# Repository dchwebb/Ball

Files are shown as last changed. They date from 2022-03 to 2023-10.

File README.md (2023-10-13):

# Ball
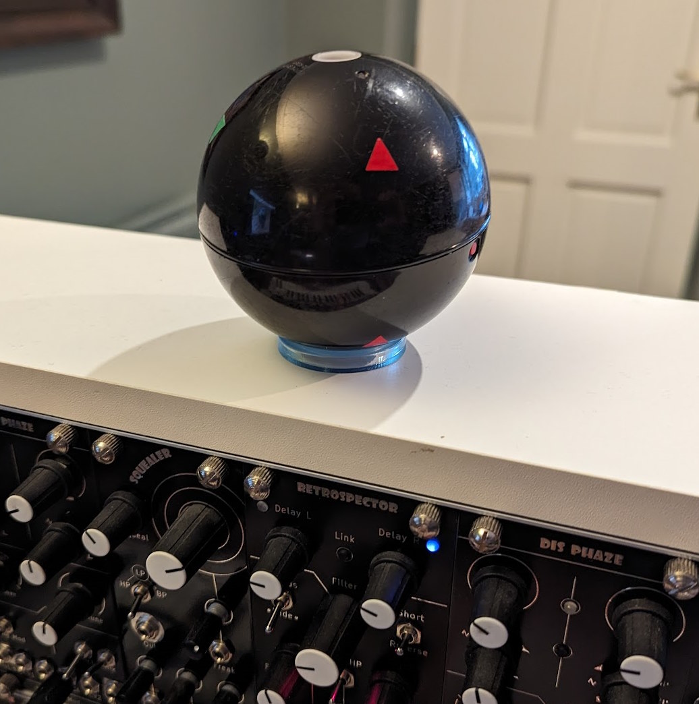
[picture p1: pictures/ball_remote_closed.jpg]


Overview
--------

Ball is a Bluetooth remote controller for a Eurorack modular synthesiser. The remote controller is a sphere containing a PCB with an STM32WB35 BLE transmitter connected to an STM MEMS gyroscope. The remote communicates over Bluetooth Low Energy (BLE) with a base unit. The base unit is a standard Eurorack module that converts the three axis gyroscope information into three control voltages.

Remote
------

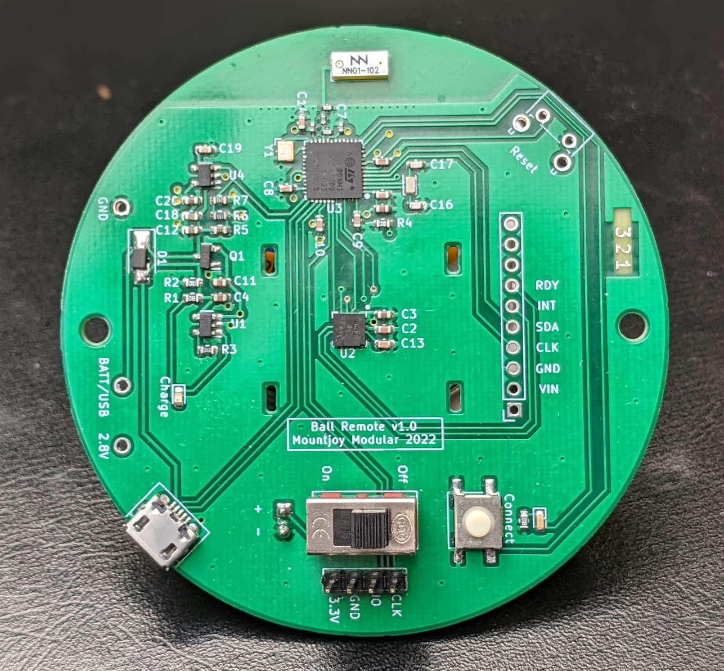
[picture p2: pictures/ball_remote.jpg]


The remote unit is designed around an STM32WB35 and powered from a Li-Po battery which is charged via a USB micro connection. Battery charging uses a MCP73831 Microchip Charge Management Controller. The battery can be isolated with a slide switch. A mosfet switches either the battery or USB power to a 2.8V linear regulator to power the MCU and gyroscope. A combined voltage divider passes the scaled battery voltage to an ADC in the MCU for battery level monitoring. The voltage divider also controls the inhibit line on the LDO to avoid drawing excessive power from the battery.

The 3-D sensing is carried out on an L3GD20 MEMS gyroscope from STM. This communicates with the MCU via full-duplex SPI. Initial prototyping was carried out using I2C on an Adafruit module and the pins for connecting to the module are fitted to the prototype board. The pins exposing the gyroscope ready and interrupt were bodged into the design via the (now unused) I2C pins. This allows waking from sleep mode via motion detection and readings to be taken from the gyroscope as soon as the ready interrupt fires.

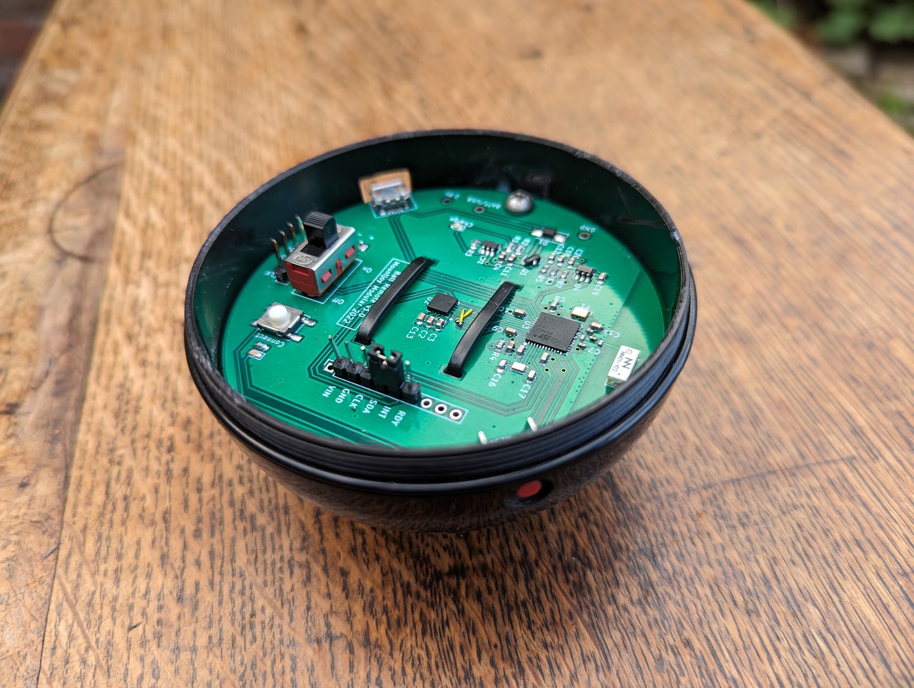
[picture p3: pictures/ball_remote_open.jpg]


The prototype Remote unit was fitted to a black sphere requisitioned from a child's toy.

[Schematic](https://raw.githubusercontent.com/dchwebb/Ball/main/ball_remote_schematic.pdf)

Base Unit
---------

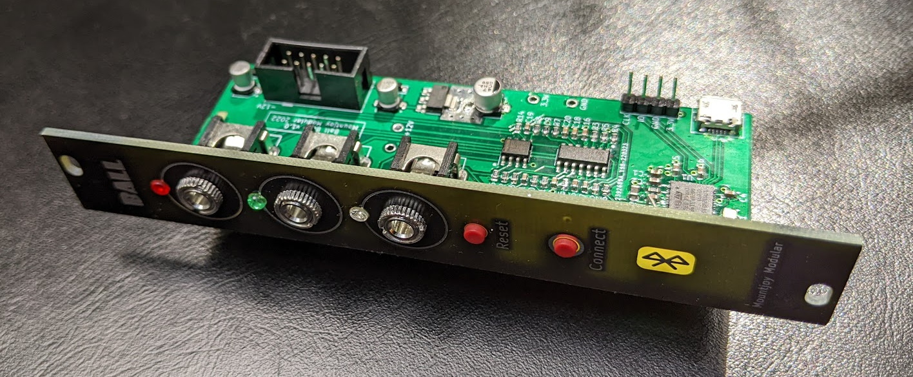
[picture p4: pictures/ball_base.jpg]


The base unit also features an STM32WB35. This receives the 3 dimensional gyroscope data from the remote unit over BLE using the HID Joystick specification. (Theoretically this should mean the unit could also support other BLE game controllers but this has not been tested.)

The STM32WB does not contain any DACs so the gyroscope XYZ data is supplied as PWM data which is filtered and scaled to 0-5V. Three LEDs display the current level of each CV output. An additional blue LED showing BLE connection status is positioned behind a PCB Bluetooth 'window' - ie shines through the FR4 with no solder mask or copper.

[Schematic](https://raw.githubusercontent.com/dchwebb/Ball/main/ball_base_schematic.pdf)

Antennas and Matching Network
-----------------------------

The antenna matching network was designed using largely application notes and guesswork. The matching network consists of an 0402 PI network of capacitor/inductor/capacitor connected to an Ignion NN01_102 antenna. Whilst connection strength could probably be improved if matched with a VNA, communications work well in testing.

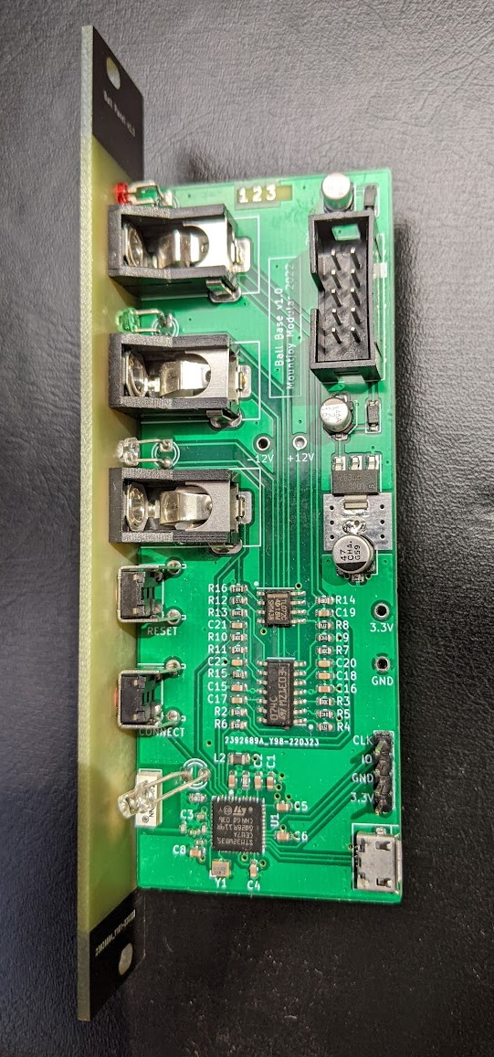
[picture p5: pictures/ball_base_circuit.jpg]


Power Management and Sleep
--------------------------

As the Remote unit is battery powered various systems are used to reduce power consumption:

When the unit is first powered or reset it begins fast advertising which allows for near-instant connections. After a configurable period has elapsed the unit switches to more infrequent advertising. After a further configurable period of inactivity the unit enters shutdown and can be restarted via the reset button.

Once a connection has been established to the base unit the remote will transmit at full speed (around 380Hz). If no motion is detected after a few seconds the unit will slow down the sampling rate to 190Hz and if no motion is detected after a few more seconds will enter sleep mode. The device can woken via motion (using the gyroscope's interrupt pin), or from the base unit (ie to request a battery level update). If woken from motion the sleep process will repeat once the unit is at rest, or if woken via RF will immediately return to sleep.

The Remote unit's USB peripheral is disabled unless a battery reading of 100% is registered (ie the unit is connected to USB and powered via VBUS). If USB is enabled current draw is around 2mA higher than usual. a USB serial command will also momentarily wake the unit if sleeping.

Measured current consumption of the remote (MCU and all other hardware) is measured as approximately:

- Advertising: 13mA
- Connected: 16mA
- Sleep: 10mA
- Shutdown: 0.4mA

USB Serial Console
------------------

Both the base and remote have USB serial consoles providing a range of diagnostic and configuration information:

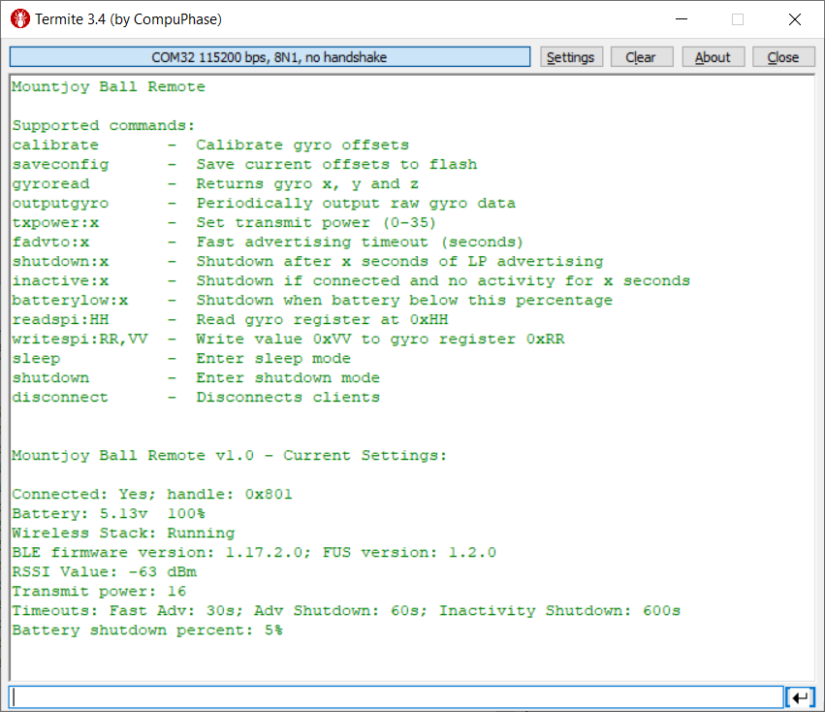
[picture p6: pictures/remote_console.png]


Development Software
--------------------

- Schematic and PCB design done in Kicad v6/7.
- Firmware developed in STM32CubeIDE v1.13.2.

Errata
------

Remote:

- SPI MOSI and MISO connections swapped
- Gyroscope Interrupt and Ready pins bodged onto unused I2C pins
- Mosfet Q1 source and drain pins swapped
- Battery charging and monitoring circuit could be improved (eg using a dedicated Battery Management IC such as TI's BQ24079QWRGTRQ1)

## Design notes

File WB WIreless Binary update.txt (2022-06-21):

- Binary locations
C:\Users\Dominic\STM32Cube\Repository\STM32Cube_FW_WB_V1.13.3\Projects\STM32WB_Copro_Wireless_Binaries\STM32WB3x

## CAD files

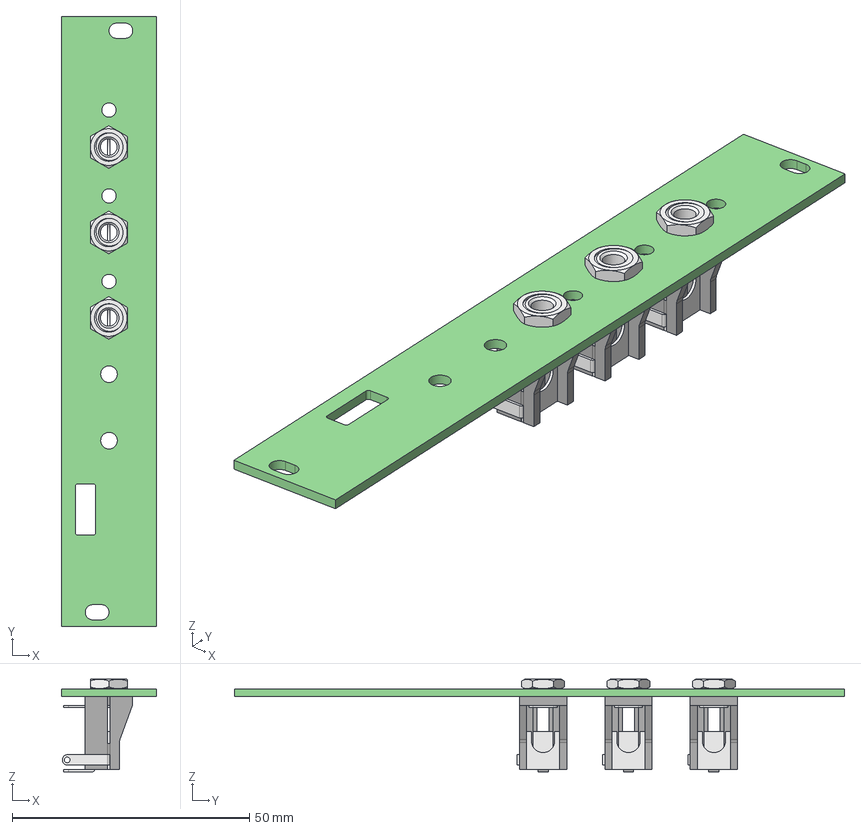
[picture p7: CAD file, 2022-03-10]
Hardware/Graphics/Ball_Base_Panel.step
20.0 x 128.5 x 19.5 mm
Ball_Base_Panel PCB

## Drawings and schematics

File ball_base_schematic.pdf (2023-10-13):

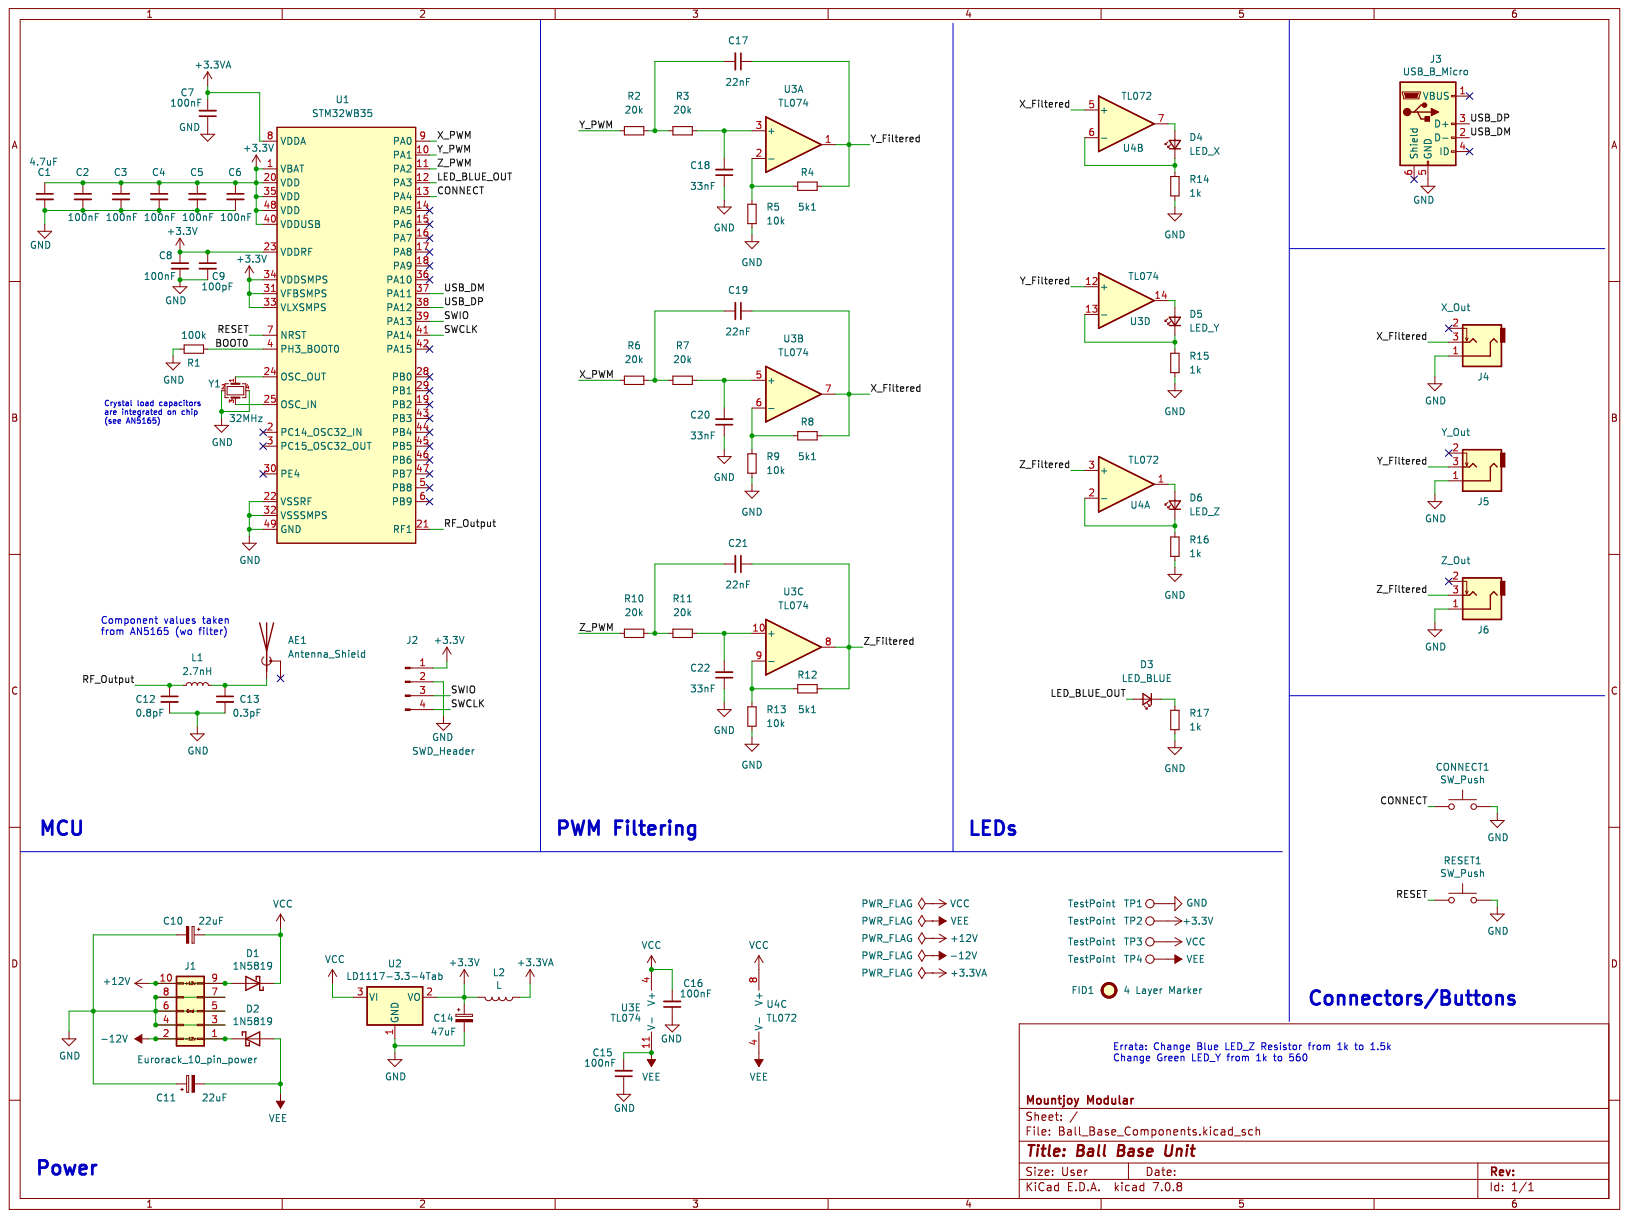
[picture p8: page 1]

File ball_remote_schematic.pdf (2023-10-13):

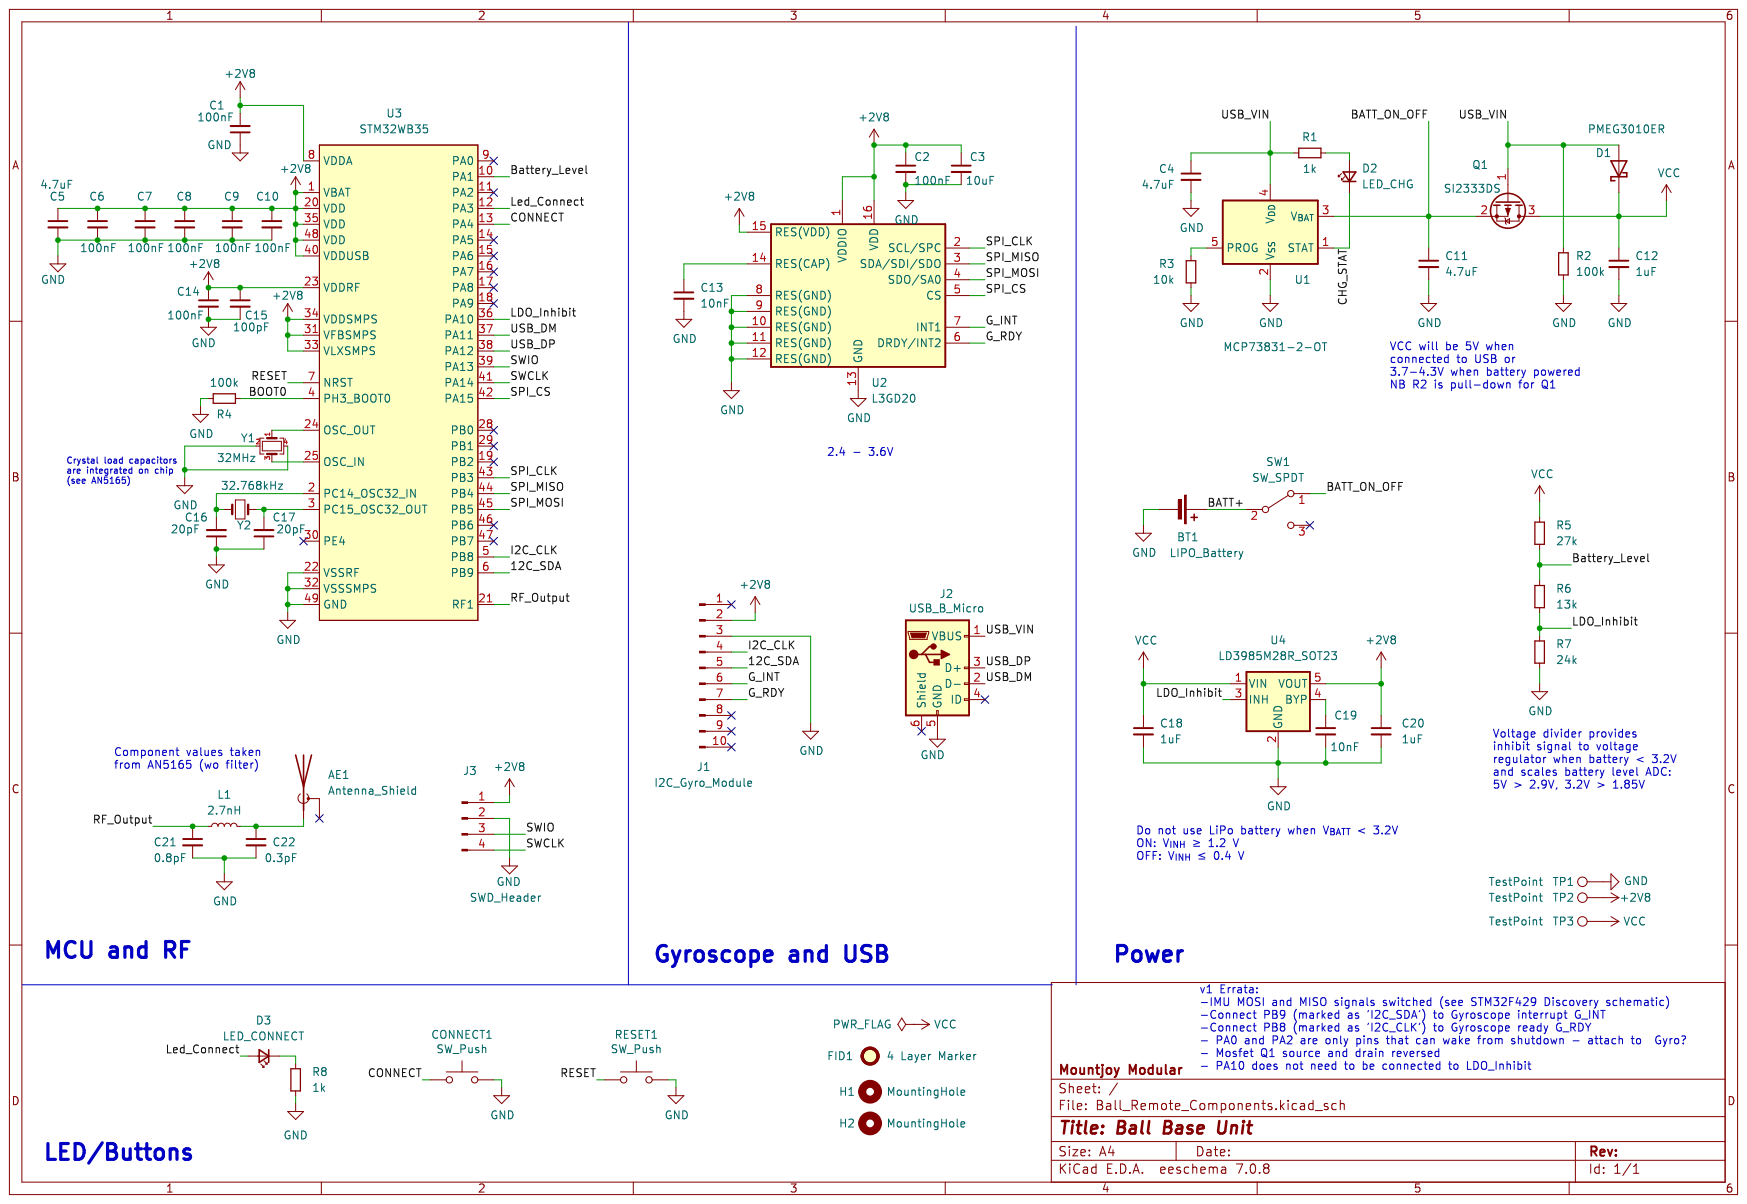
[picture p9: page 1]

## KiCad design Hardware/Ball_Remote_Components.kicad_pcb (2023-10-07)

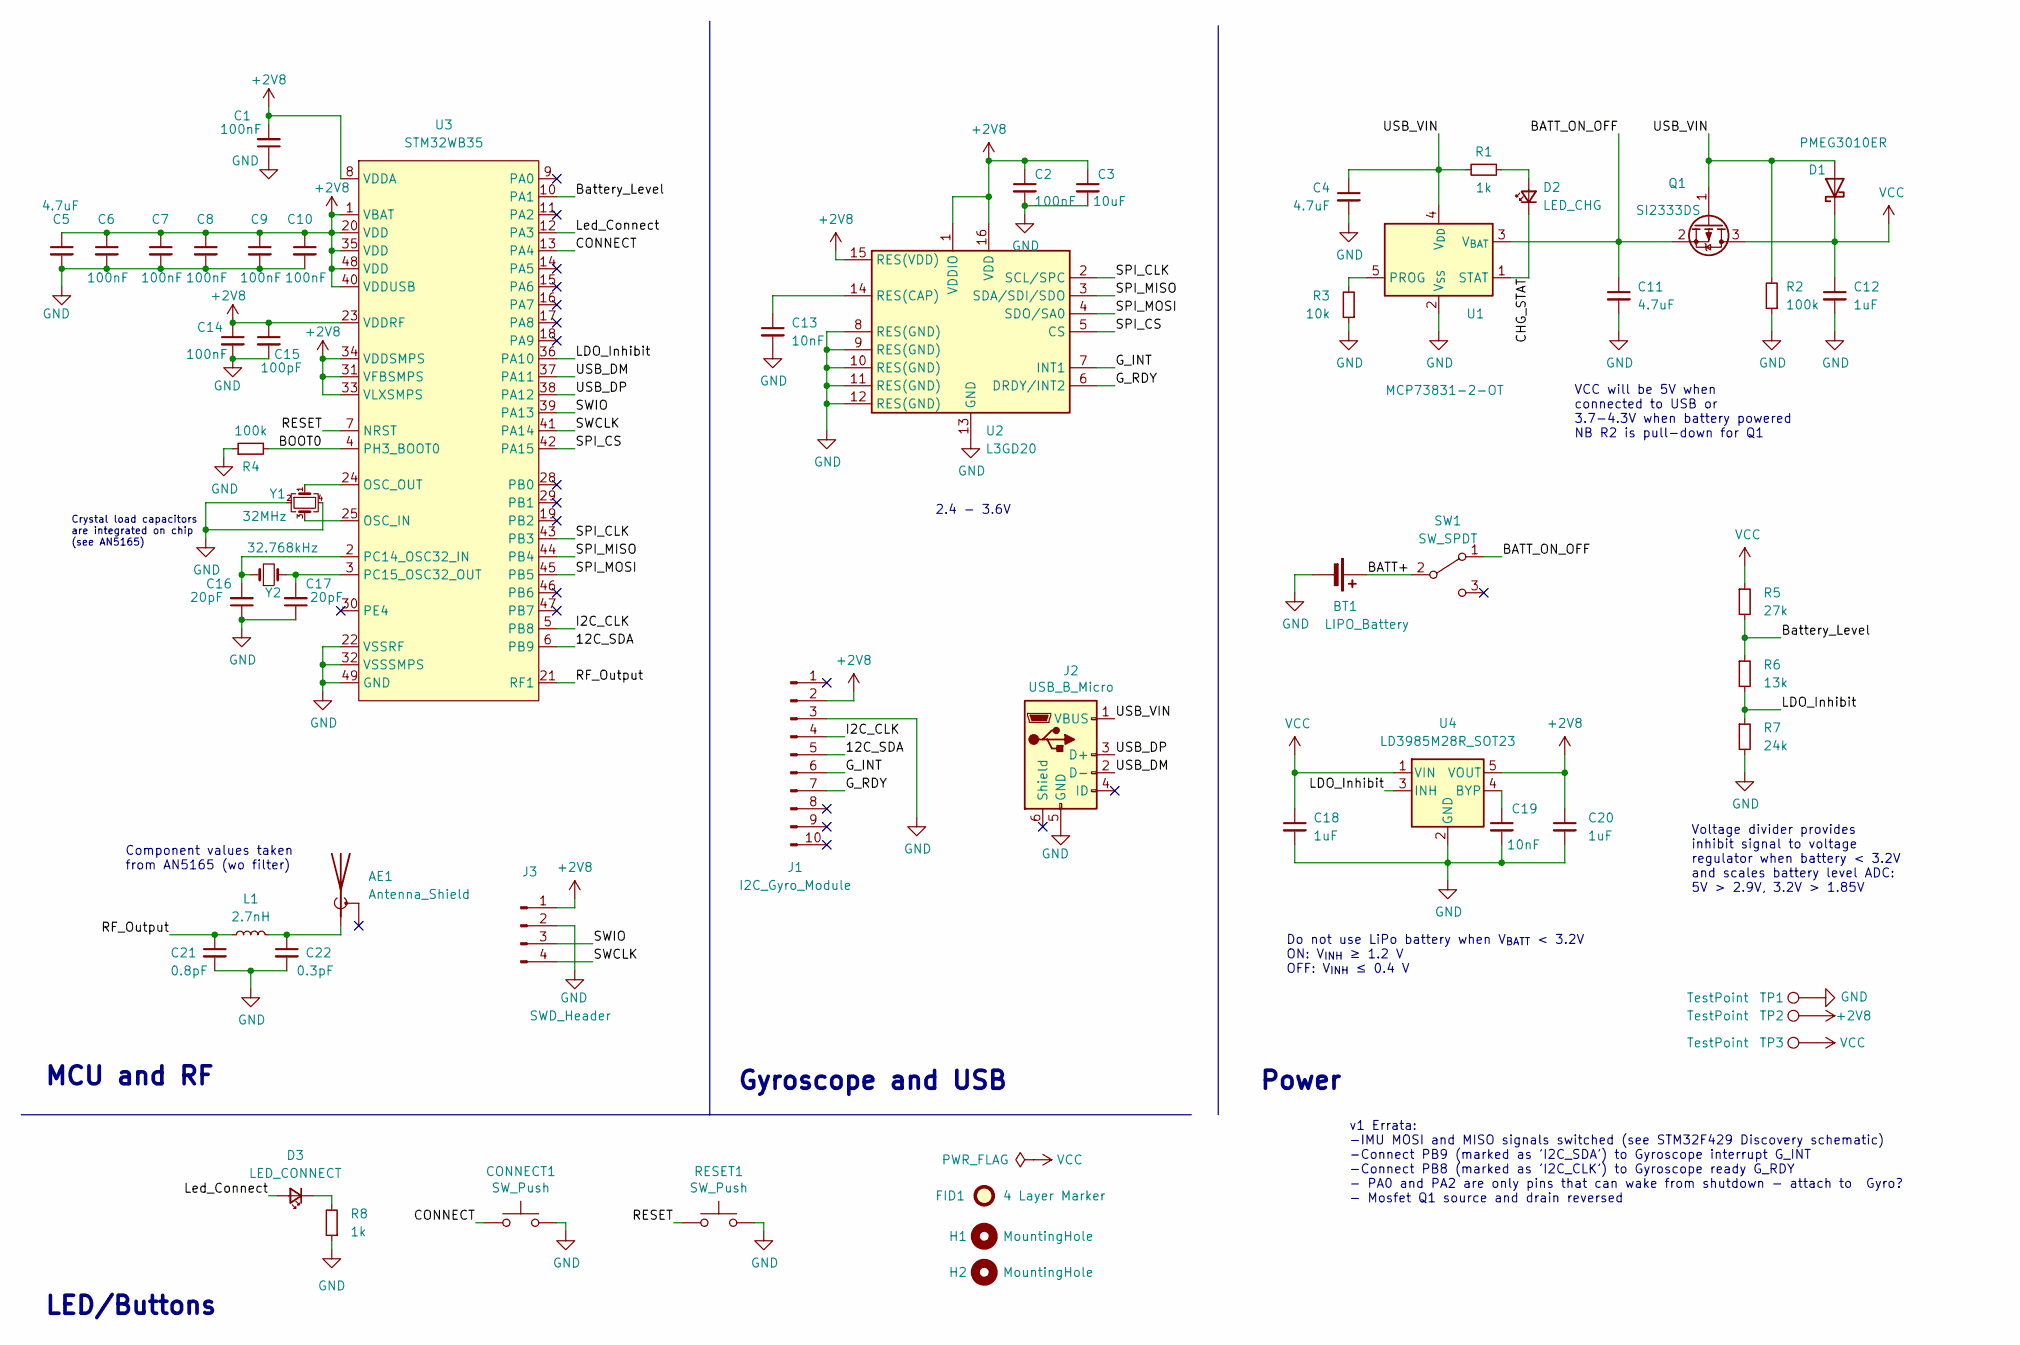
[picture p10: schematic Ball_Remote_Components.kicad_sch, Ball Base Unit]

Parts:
AE1: Antenna_Shield; NN01_102
BT1: LIPO_Battery; PinHeader_1x02_P2.54mm_Vertical
C1, C2, C6, C8, C9, C10, C14: 100nF; C_0603_1608Metric
C3: 10uF; C_0603_1608Metric
C4, C5, C11: 4.7uF; C_0603_1608Metric
C7: 100nF; C_0402_1005Metric
C12, C18, C20: 1uF; C_0603_1608Metric
C13, C19: 10nF; C_0603_1608Metric
C15: 100pF; C_0402_1005Metric
C16, C17: 20pF; C_0603_1608Metric
C21: 0.8pF; C_0402_1005Metric
C22: 0.3pF; C_0402_1005Metric
CONNECT1: SW_Push; SW_SPST_EVQQ2
D1: PMEG3010ER; D_SMA
D2: LED_CHG; LED_0603_1608Metric
D3: LED_CONNECT; LED_0603_1608Metric
FID1: 4 Layer Marker; 4_Layer_Markers
H1, H2: MountingHole; MountingHole_3.2mm_M3
J1: I2C_Gyro_Module; PinSocket_1x10_P2.54mm_Vertical
J2: USB_B_Micro; USB_Micro-B_Amphenol
J3: SWD_Header; SWD_header
L1: 2.7nH; L_0402_1005Metric
Q1: SI2333DS; SOT-23
R1: 1k; R_0603_1608Metric; Part_Number C25803
R2, R4: 100k; R_0603_1608Metric; Part_Number C25803
R3: 10k; R_0603_1608Metric; Part_Number C25803
R5: 27k; R_0603_1608Metric; Part_Number C25803
R6: 13k; R_0603_1608Metric; Part_Number C25803
R7: 24k; R_0603_1608Metric; Part_Number C25803
R8: 1k; R_0603_1608Metric
RESET1: SW_Push; SW_Tactile_SPST_Angled_PTS645Vx58-2LFS
SW1: SW_SPDT; SPDT_Slide_Switch
TP1, TP2, TP3: TestPoint; 1.3mm_Test_Point
U1: MCP73831-2-OT; SOT-23-5
U2: L3GD20; LGA-16_4x4mm_P0.65mm_LayoutBorder4x4y
U3: STM32WB35; QFN-48-1EP_7x7mm_P0.5mm_EP5.15x5.15mm_ThermalVias
U4: LD3985M28R_SOT23; SOT-23-5
Y1: 32MHz; Crystal_SMD_Abracon_ABM10-4Pin_2.5x2.0mm
Y2: 32.768kHz; Crystal_SMD_2012-2Pin_2.0x1.2mm

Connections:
+2V8: C1.2, C2.1, C3.1, C5.1, C6.1, C7.1, C8.1, C9.1, C10.1, C14.1, C15.1, C20.1, J1.2, J3.1, TP2.1, U2.1 (VDDIO), U2.15 (RES(VDD)), U2.16 (VDD), U3.1 (VBAT), U3.8 (VDDA), U3.20 (VDD), U3.23 (VDDRF), U3.31 (VFBSMPS), U3.33 (VLXSMPS), U3.34 (VDDSMPS), U3.35 (VDD), U3.40 (VDDUSB), U3.48 (VDD), U4.5 (VOUT)
/12C_SDA: J1.5, U3.6 (PB9)
/BATT+: BT1.1 (+), SW1.2 (B)
/BATT_ON_OFF: C11.1, Q1.2 (S), SW1.1 (A), U1.3 (V_{BAT})
/BOOT0: R4.2, U3.4 (PH3_BOOT0)
/Battery_Level: R5.2, R6.1, U3.10 (PA1)
/CHG_STAT: D2.1 (K), U1.1 (STAT)
/CONNECT: CONNECT1.1, U3.13 (PA4)
/G_INT: J1.6, U2.7 (INT1)
/G_RDY: J1.7, U2.6 (DRDY/INT2)
/I2C_CLK: J1.4, U3.5 (PB8)
/LDO_Inhibit: R6.2, R7.1, U3.36 (PA10), U4.3 (INH)
/Led_Connect: D3.2 (A), U3.12 (PA3)
/RESET: RESET1.1, U3.7 (NRST)
/RF_Output: C21.1, L1.1, U3.21 (RF1)
/SPI_CLK: U2.2 (SCL/SPC), U3.43 (PB3)
/SPI_CS: U2.5 (CS), U3.42 (PA15)
/SPI_MISO: U2.3 (SDA/SDI/SDO), U3.44 (PB4)
/SPI_MOSI: U2.4 (SDO/SA0), U3.45 (PB5)
/SWCLK: J3.4, U3.41 (PA14)
/SWIO: J3.3, U3.39 (PA13)
/USB_DM: J2.2 (D-), U3.37 (PA11)
/USB_DP: J2.3 (D+), U3.38 (PA12)
/USB_VIN: C4.1, D1.2 (A), J2.1 (VBUS), Q1.1 (G), R1.2, R2.2, U1.4 (V_{DD})
GND: BT1.2 (-), C1.1, C2.2, C3.2, C4.2, C5.2, C6.2, C7.2, C8.2, C9.2, C10.2, C11.2, C12.2, C13.2, C14.2, C15.2, C16.1, C17.1, C18.2, C19.2, C20.2, C21.2, C22.2, CONNECT1.2, J1.3, J2.5 (GND), J3.2, R2.1, R3.1, R4.1, R7.2, R8.1, RESET1.2, TP1.1, U1.2 (V_{SS}), U2.8 (RES(GND)), U2.9 (RES(GND)), U2.10 (RES(GND)), U2.11 (RES(GND)), U2.12 (RES(GND)), U2.13 (GND), U3.22 (VSSRF), U3.32 (VSSSMPS), U3.49 (GND), U4.2 (GND), Y1.2, Y1.4
unnamed: AE1.1 (A), C22.1, L1.2
unnamed: D2.2 (A), R1.1
unnamed: D3.1 (K), R8.2
unnamed: R3.2, U1.5 (PROG)
unnamed: C13.1, U2.14 (RES(CAP))
unnamed: U3.25 (OSC_IN), Y1.3
unnamed: U3.24 (OSC_OUT), Y1.1
unnamed: C16.2, U3.2 (PC14_OSC32_IN), Y2.1
unnamed: C17.2, U3.3 (PC15_OSC32_OUT), Y2.2
unnamed: C19.1, U4.4 (BYP)
VCC: C12.1, C18.1, D1.1 (K), Q1.3 (D), R5.1, TP3.1, U4.1 (VIN)

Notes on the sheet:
MCU and RF
Do not use LiPo battery when V_{BATT} < 3.2V ON: V_{INH} ≥ 1.2 V OFF: V_{INH} ≤ 0.4 V
Power
Gyroscope and USB
Component values taken from AN5165 (wo filter)
Voltage divider provides inhibit signal to voltage regulator when battery < 3.2V and scales battery level ADC: 5V > 2.9V, 3.2V > 1.85V
2.4 - 3.6V
LED/Buttons
VCC will be 5V when connected to USB or 3.7-4.3V when battery powered NB R2 is pull-down for Q1
v1 Errata: -IMU MOSI and MISO signals switched (see STM32F429 Discovery schematic) -Connect PB9 (marked as 'I2C_SDA') to Gyroscope interrupt G_INT -Connect PB8 (marked as 'I2C_CLK') to Gyroscope ready G_RDY - PA0 and PA2 are only pins that can wake from shutdown - attach to Gyro? - Mosfet Q1 source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
Crystal load capacitors are integrated on chip (see AN5165)

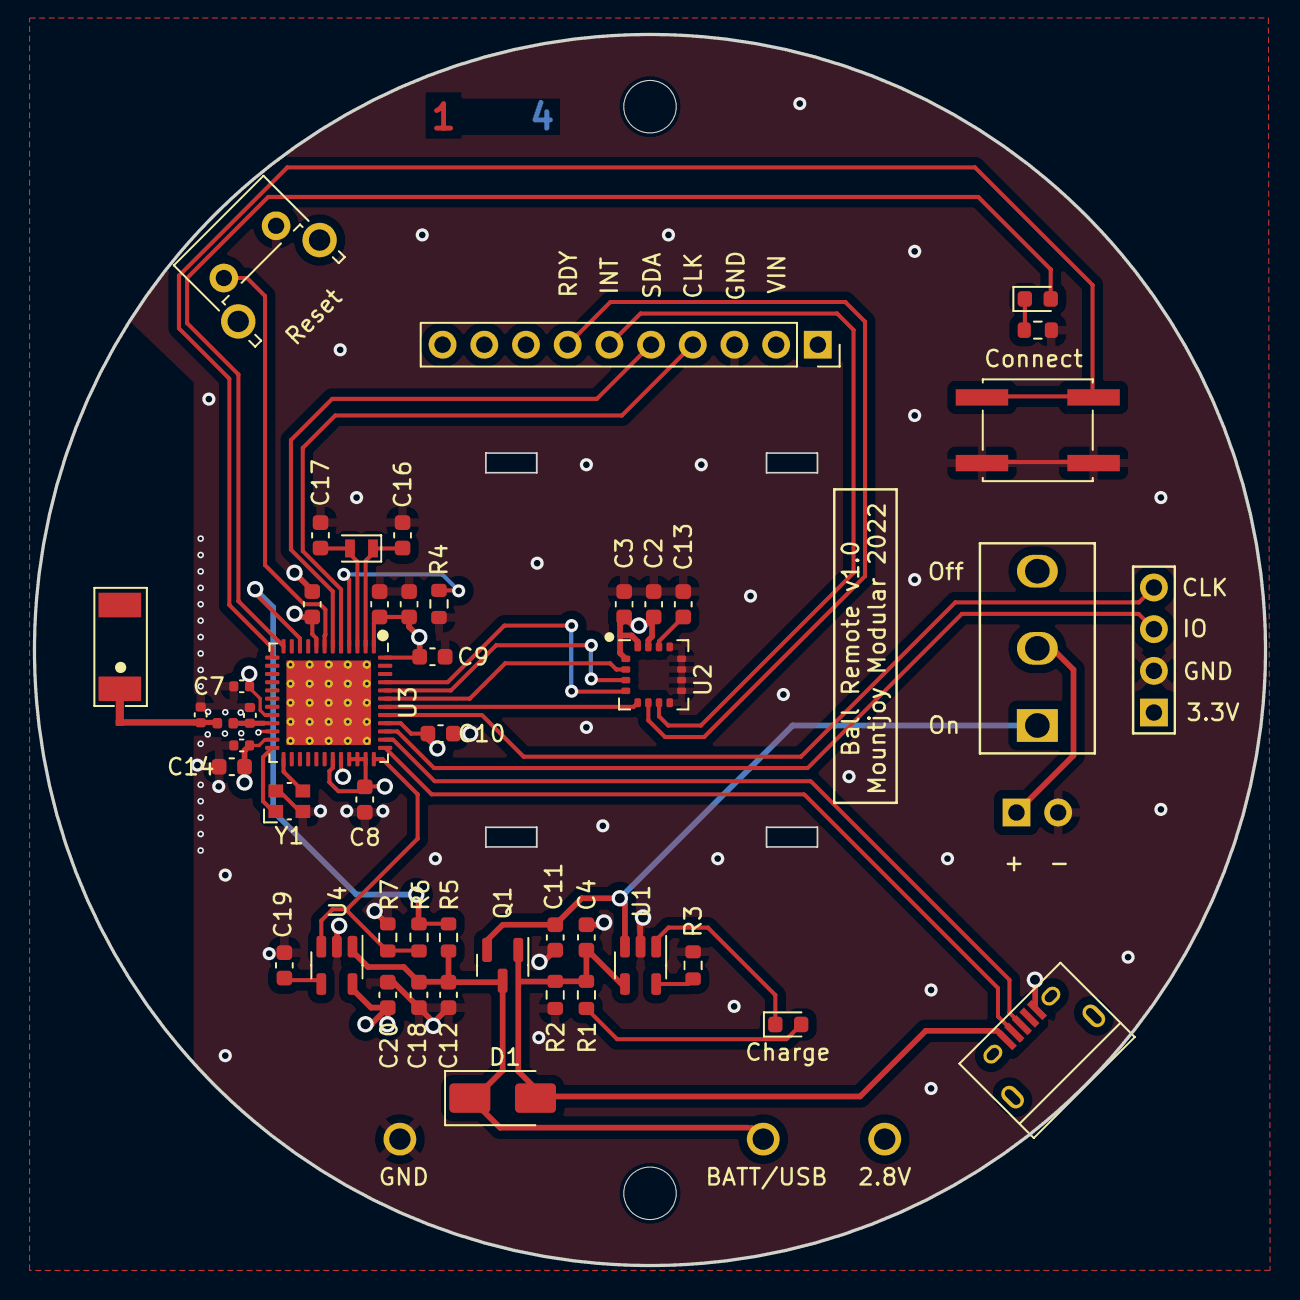
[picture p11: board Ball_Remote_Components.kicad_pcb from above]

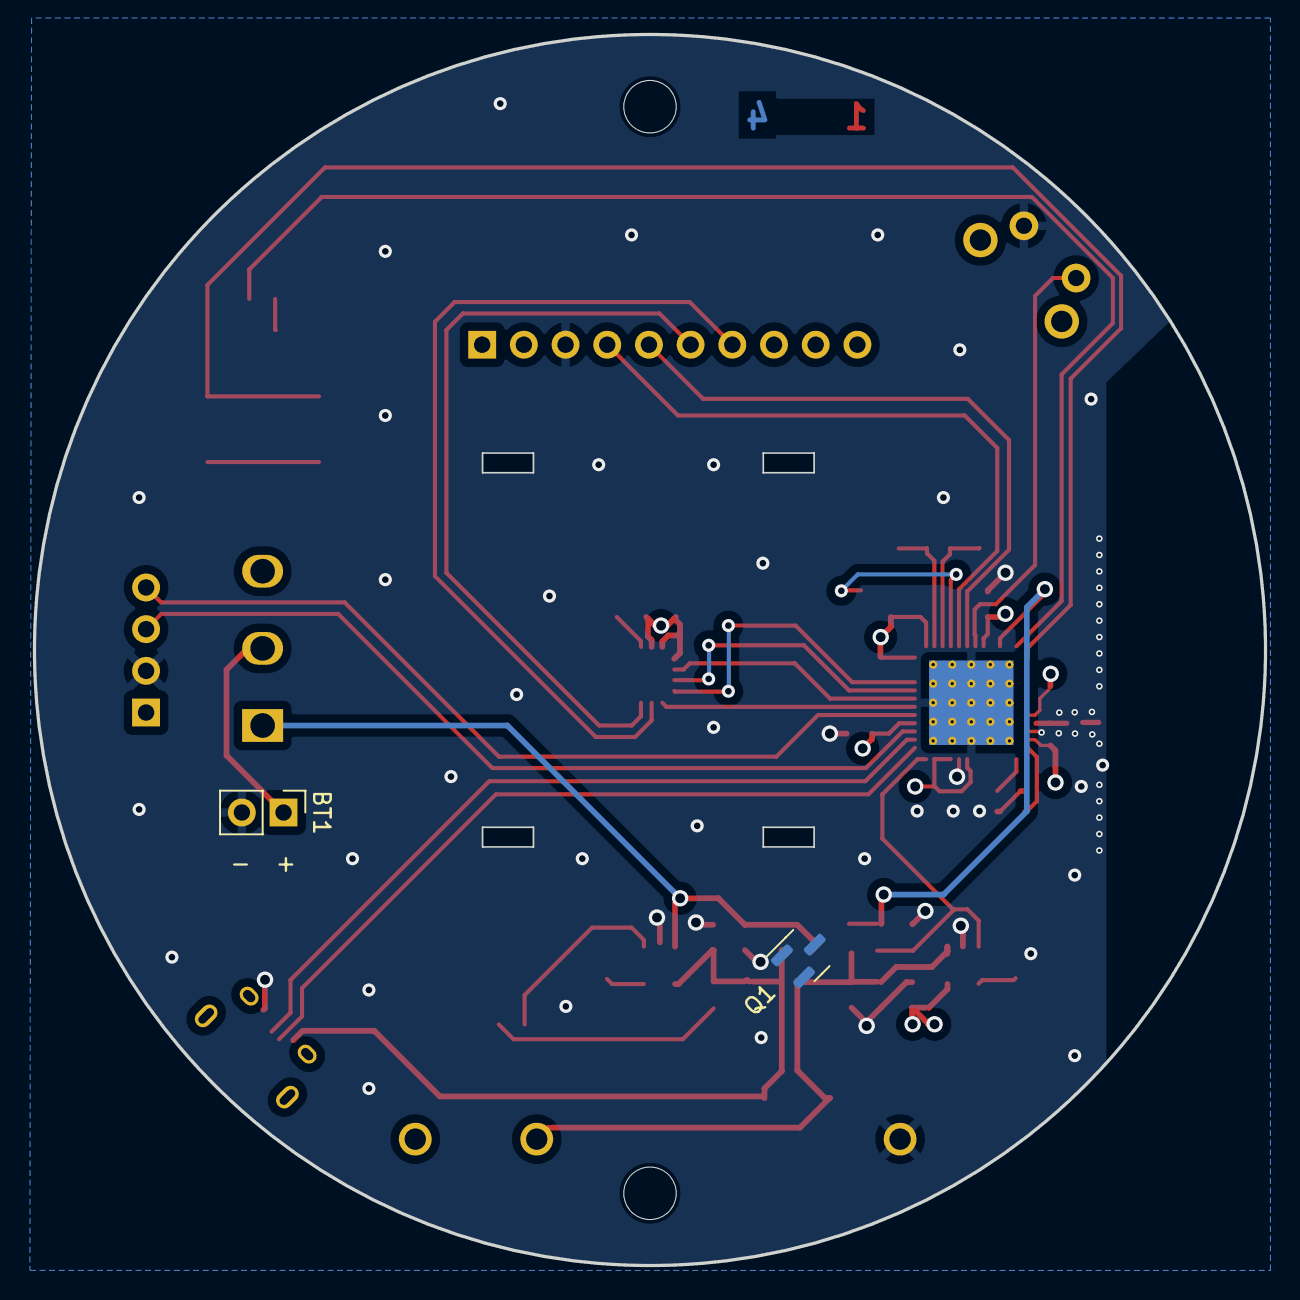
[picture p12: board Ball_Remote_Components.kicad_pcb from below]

Board: 4 copper layers, 75.0 x 75.0 mm, 56 parts (2 on the bottom side), 36 nets.

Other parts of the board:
Q1#2: SI2333DS; SOT-23

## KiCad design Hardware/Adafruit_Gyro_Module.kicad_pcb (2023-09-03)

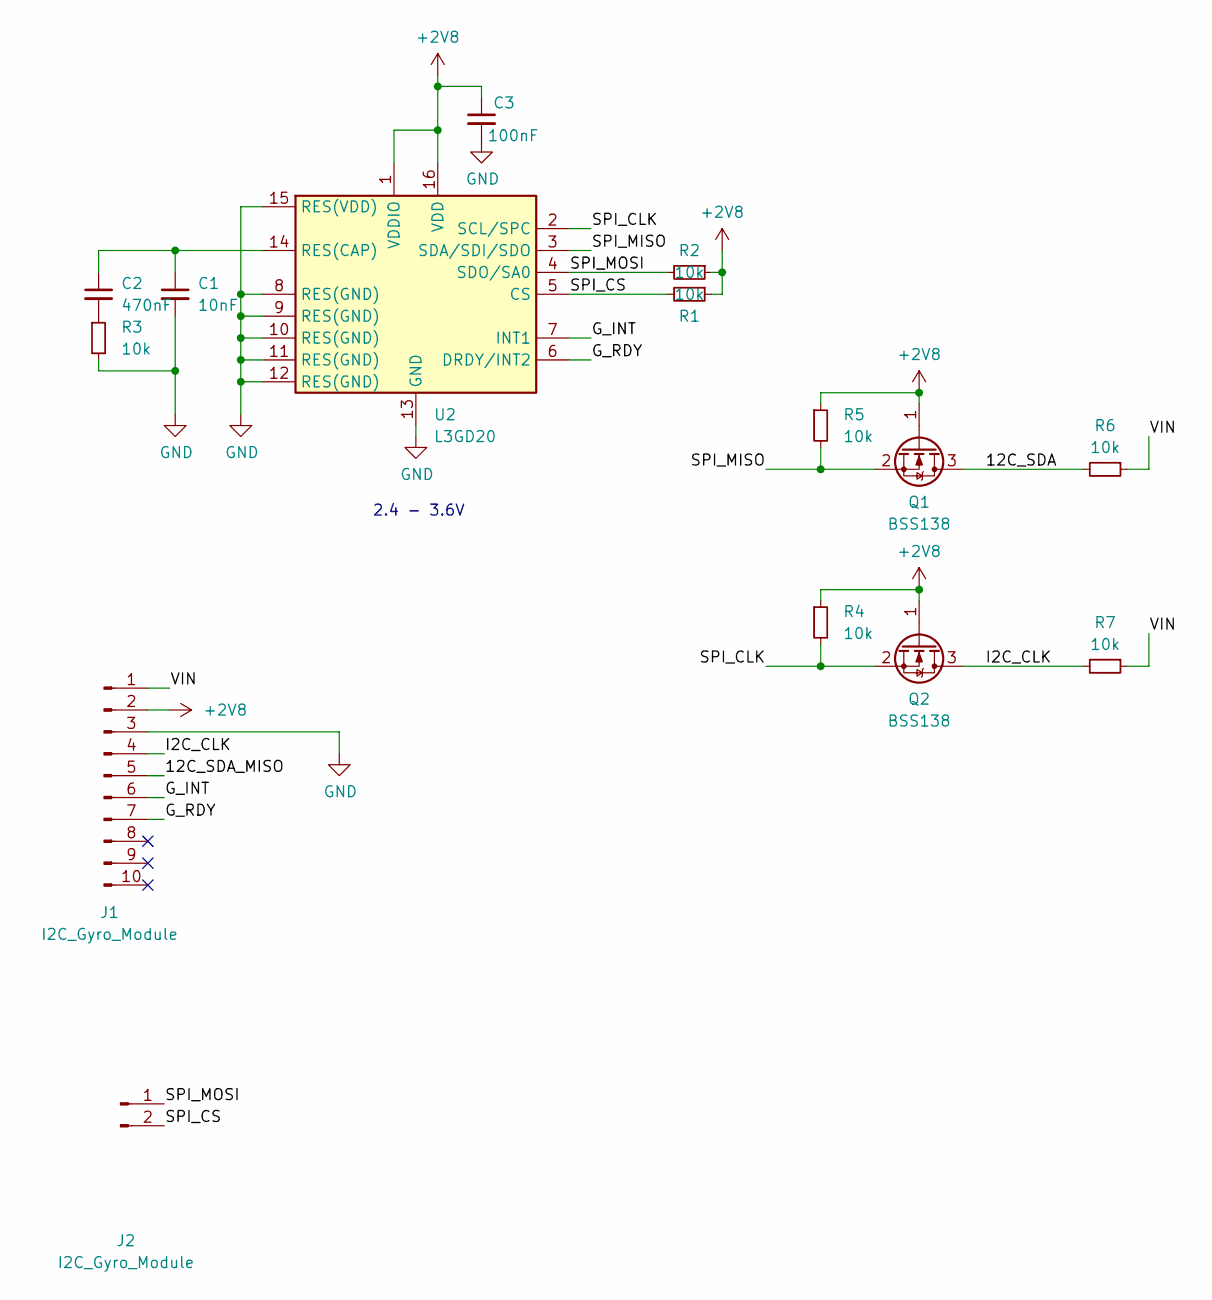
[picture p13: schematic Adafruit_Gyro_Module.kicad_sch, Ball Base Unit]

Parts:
C1: 10nF; C_0603_1608Metric
C2: 470nF; C_0603_1608Metric
C3: 100nF; C_0603_1608Metric
J1: I2C_Gyro_Module; PinSocket_1x10_P2.54mm_Vertical
J2: I2C_Gyro_Module; PinSocket_1x02_P2.54mm_Vertical
Q1, Q2: BSS138; SOT-23
R1, R2, R3, R4, R5, R6, R7: 10k; R_0603_1608Metric; Part_Number C25803
U2: L3GD20; LGA-16_4x4mm_P0.65mm_LayoutBorder4x4y

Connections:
+2V8: C3.1, J1.2, Q1.1 (G), Q2.1 (G), R1.1, R2.1, R4.1, R5.1, U2.1 (VDDIO), U2.16 (VDD)
/12C_SDA: Q1.3 (D), R6.2
/12C_SDA_MISO: J1.5
/G_INT: J1.6, U2.7 (INT1)
/G_RDY: J1.7, U2.6 (DRDY/INT2)
/I2C_CLK: J1.4, Q2.3 (D), R7.2
/SPI_CLK: Q2.2 (S), R4.2, U2.2 (SCL/SPC)
/SPI_CS: J2.2, R1.2, U2.5 (CS)
/SPI_MISO: Q1.2 (S), R5.2, U2.3 (SDA/SDI/SDO)
/SPI_MOSI: J2.1, R2.2, U2.4 (SDO/SA0)
/VIN: J1.1, R6.1, R7.1
GND: C1.2, C3.2, J1.3, R3.2, U2.8 (RES(GND)), U2.9 (RES(GND)), U2.10 (RES(GND)), U2.11 (RES(GND)), U2.12 (RES(GND)), U2.13 (GND), U2.15 (RES(VDD))
unnamed: C2.2, R3.1
unnamed: C1.1, C2.1, U2.14 (RES(CAP))

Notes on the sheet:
2.4 - 3.6V

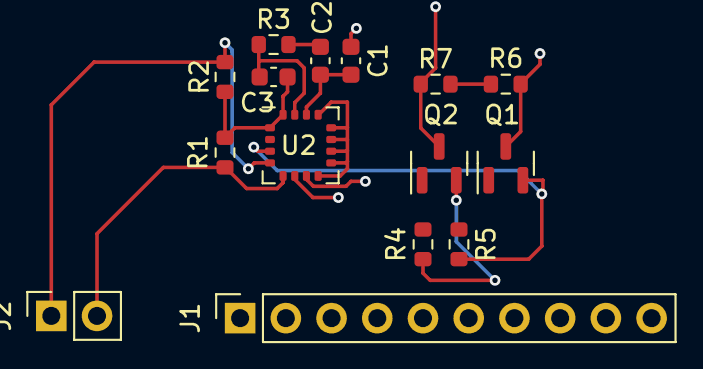
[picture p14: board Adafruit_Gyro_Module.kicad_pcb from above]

Board: 2 copper layers, 15 parts (0 on the bottom side), 13 nets.

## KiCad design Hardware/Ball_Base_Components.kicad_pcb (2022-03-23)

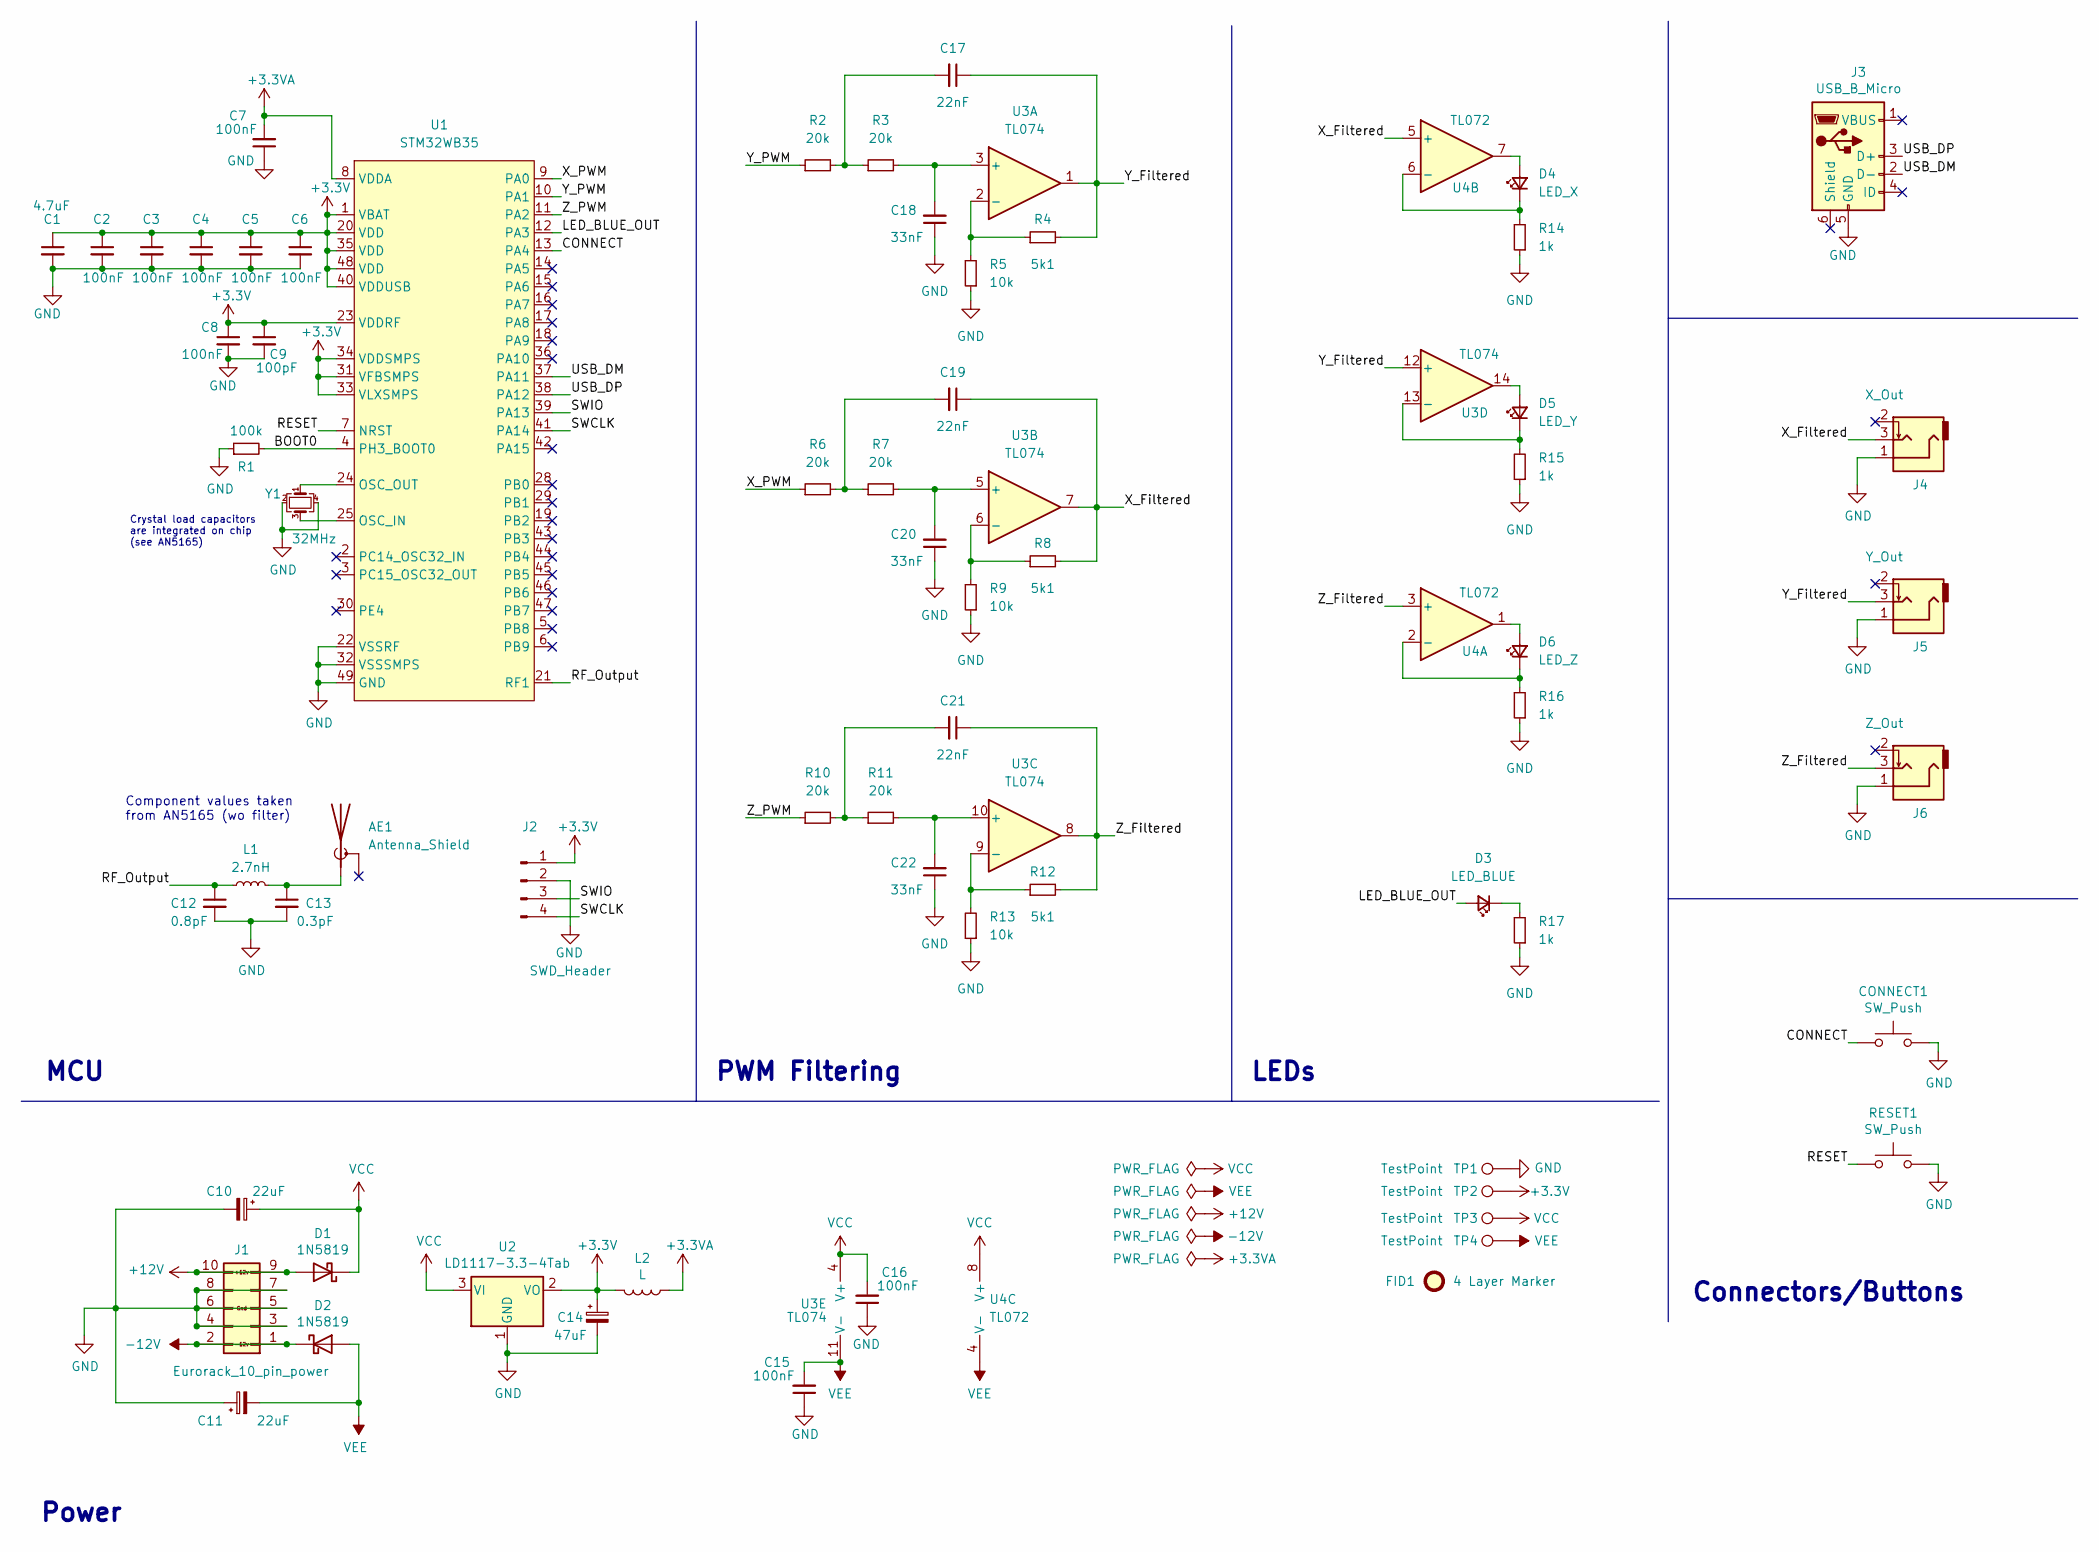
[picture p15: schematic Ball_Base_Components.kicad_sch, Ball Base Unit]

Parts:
AE1: Antenna_Shield; NN01_102
C1: 4.7uF; C_0603_1608Metric
C2, C4, C5, C6, C7, C8, C15, C16: 100nF; C_0603_1608Metric
C3: 100nF; C_0402_1005Metric
C9: 100pF; C_0402_1005Metric
C10: 22uF; CP_Elec_4x5.4; Part_Number C134798
C11: 22uF; CP_Elec_4x5.4; Part_Number C134793
C12: 0.8pF; C_0402_1005Metric
C13: 0.3pF; C_0402_1005Metric
C14: 47uF; CP_Elec_5x5.8; Part_Number C134798
C17, C19, C21: 22nF; C_0603_1608Metric
C18, C20, C22: 33nF; C_0603_1608Metric
CONNECT1: SW_Push; SW_Tactile_SPST_Angled_PTS645Vx58-2LFS
D1, D2: 1N5819; D_SOD-123; Part_Number C8598
D3: LED_BLUE; LED_D3.0mm_FlatTop
D4: LED_X; LED_D3.0mm_FlatTop
D5: LED_Y; LED_D3.0mm_FlatTop
D6: LED_Z; LED_D3.0mm_FlatTop
FID1: 4 Layer Marker; 4_Layer_Markers
J1: Eurorack_10_pin_power; Eurorack_10_pin_header
J2: SWD_Header; SWD_header
J3: USB_B_Micro; USB_Micro-B_Amphenol
J4: X_Out; Jack_3.5mm_QingPu_WQP-PJ302M_Horizontal
J5: Y_Out; Jack_3.5mm_QingPu_WQP-PJ302M_Horizontal
J6: Z_Out; Jack_3.5mm_QingPu_WQP-PJ302M_Horizontal
L1: 2.7nH; L_0402_1005Metric
L2: L; L_0805_2012Metric; Part_Number C1046
R1: 100k; R_0603_1608Metric; Part_Number C25803
R2, R3, R6, R7, R10, R11: 20k; R_0603_1608Metric
R4, R8, R12: 5k1; R_0603_1608Metric
R5, R9, R13: 10k; R_0603_1608Metric
R14, R15, R16, R17: 1k; R_0603_1608Metric
RESET1: SW_Push; SW_Tactile_SPST_Angled_PTS645Vx58-2LFS
TP1, TP2, TP3, TP4: TestPoint; 1.3mm_Test_Point
U1: STM32WB35; QFN-48-1EP_7x7mm_P0.5mm_EP5.15x5.15mm_ThermalVias
U2: LD1117-3.3-4Tab; SOT-223-3_TabPin2
U3: TL074; SOIC-14_3.9x8.7mm_P1.27mm
U4: TL072; SOIC-8_3.9x4.9mm_P1.27mm
Y1: 32MHz; Crystal_SMD_Abracon_ABM10-4Pin_2.5x2.0mm

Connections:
+3.3VA: C7.2, L2.1, U1.8 (VDDA)
+3V3: C1.1, C2.1, C3.1, C4.1, C5.1, C6.1, C8.1, C9.1, C14.1, J2.1, L2.2, TP2.1, U1.1 (VBAT), U1.20 (VDD), U1.23 (VDDRF), U1.31 (VFBSMPS), U1.33 (VLXSMPS), U1.34 (VDDSMPS), U1.35 (VDD), U1.40 (VDDUSB), U1.48 (VDD), U2.2 (VO)
+12V: D1.2 (A), J1.9, J1.10
-12V: D2.1 (K), J1.1, J1.2
/BOOT0: R1.2, U1.4 (PH3_BOOT0)
/CONNECT: CONNECT1.1, U1.13 (PA4)
/LED_BLUE_OUT: D3.2 (A), U1.12 (PA3)
/RESET: RESET1.1, U1.7 (NRST)
/RF_Output: C12.1, L1.1, U1.21 (RF1)
/SWCLK: J2.4, U1.41 (PA14)
/SWIO: J2.3, U1.39 (PA13)
/USB_DM: J3.2 (D-), U1.37 (PA11)
/USB_DP: J3.3 (D+), U1.38 (PA12)
/X_Filtered: C19.1, J4.3, R8.2, U3.7, U4.5 (+)
/X_PWM: R6.1, U1.9 (PA0)
/Y_Filtered: C17.1, J5.3, R4.2, U3.1, U3.12 (+)
/Y_PWM: R2.1, U1.10 (PA1)
/Z_Filtered: C21.1, J6.3, R12.2, U3.8, U4.3 (+)
/Z_PWM: R10.1, U1.11 (PA2)
GND: C1.2, C2.2, C3.2, C4.2, C5.2, C6.2, C7.1, C8.2, C9.2, C10.2, C11.1, C12.2, C13.2, C14.2, C15.1, C16.1, C18.1, C20.1, C22.1, CONNECT1.2, J1.3, J1.4, J1.5, J1.6, J1.7, J1.8, J2.2, J3.5 (GND), J4.1, J5.1, J6.1, R1.1, R5.1, R9.1, R13.1, R14.1, R15.1, R16.1, R17.1, RESET1.2, TP1.1, U1.22 (VSSRF), U1.32 (VSSSMPS), U1.49 (GND), U2.1 (GND), Y1.2, Y1.4
unnamed: AE1.1 (A), C13.1, L1.2
unnamed: C17.2, R2.2, R3.1
unnamed: C18.2, R3.2, U3.3 (+)
unnamed: C19.2, R6.2, R7.1
unnamed: C20.2, R7.2, U3.5 (+)
unnamed: C21.2, R10.2, R11.1
unnamed: C22.2, R11.2, U3.10 (+)
unnamed: D3.1 (K), R17.2
unnamed: D4.1 (K), R14.2, U4.6 (-)
unnamed: D4.2 (A), U4.7
unnamed: D5.1 (K), R15.2, U3.13 (-)
unnamed: D5.2 (A), U3.14
unnamed: D6.1 (K), R16.2, U4.2 (-)
unnamed: D6.2 (A), U4.1
unnamed: R4.1, R5.2, U3.2 (-)
unnamed: R8.1, R9.2, U3.6 (-)
unnamed: R12.1, R13.2, U3.9 (-)
unnamed: U1.24 (OSC_OUT), Y1.1
unnamed: U1.25 (OSC_IN), Y1.3
VCC: C10.1, C16.2, D1.1 (K), TP3.1, U2.3 (VI), U3.4 (V+), U4.8 (V+)
VEE: C11.2, C15.2, D2.2 (A), TP4.1, U3.11 (V-), U4.4 (V-)

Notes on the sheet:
LEDs
MCU
Power
PWM Filtering
Component values taken from AN5165 (wo filter)
Connectors/Buttons
Crystal load capacitors are integrated on chip (see AN5165)

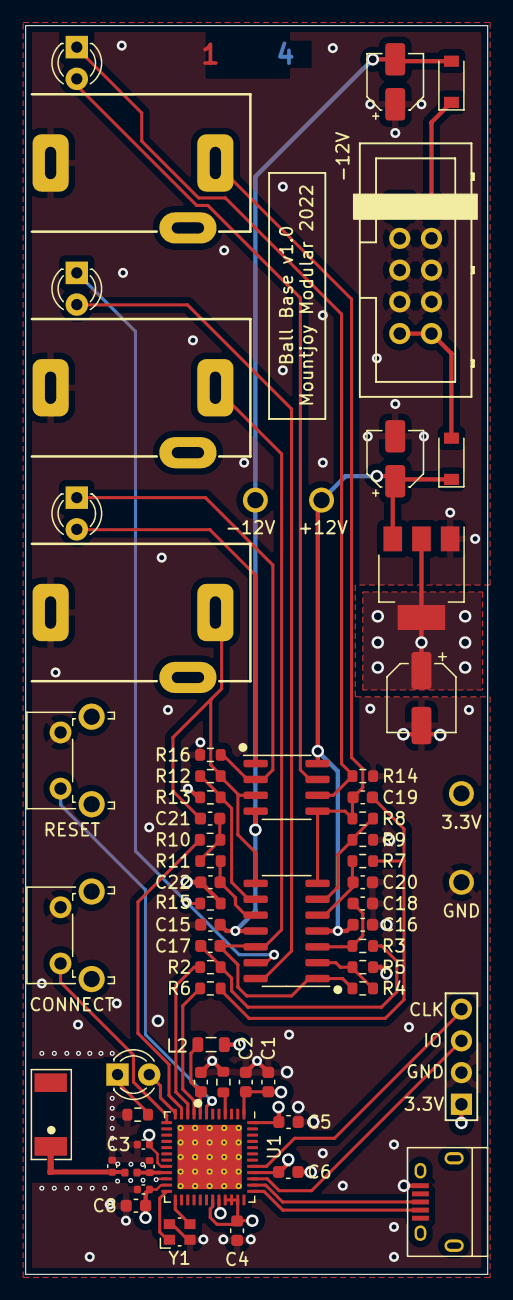
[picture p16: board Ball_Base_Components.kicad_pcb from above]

Board: 4 copper layers, 37.0 x 100.0 mm, 66 parts (0 on the bottom side), 41 nets.

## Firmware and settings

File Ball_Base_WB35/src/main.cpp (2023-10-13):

#include "initialisation.h"
#include "BleApp.h"
#include "app_entry.h"
#include "USB.h"
#include "configManager.h"
#include "led.h"
#include "HidApp.h"

// FIXME - LED keeps flashing if trying to connect with no remote module available

volatile uint32_t SysTickVal = 0;
extern uint32_t SystemCoreClock;

int main()
{
	InitClocks();					// Set system clocks
	SystemCoreClockUpdate();		// Read configured clock speed into SystemCoreClock (system clock frequency)

	InitHardware();					// Initialise HSEM, IPCC, RTC, EXTI
	usb.InitUSB();
	APPE_Init();					// Initialise low level BLE functions and schedule start of BLE in while loop
	config.RestoreConfig();
	InitPWMTimer();					// Initialise PWM output

	while (1) {
		if (!bleApp.coprocessorFailure) {
			RunPendingTasks();
		}
		usb.cdc.ProcessCommand();	// Check for incoming CDC commands
		led.Update();				// Check if connection LED needs to be flashed
		hidApp.CheckBattery();		// Run a periodic check to get battery level from remote if sleeping
	}
}

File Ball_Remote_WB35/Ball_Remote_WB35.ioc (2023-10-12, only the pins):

Mcu.UserName=STM32WB35CEUxA
PA1.Signal=ADCx_IN6
PA11.Signal=USB_DM
PA12.Signal=USB_DP
PA15.Signal=SPI1_NSS
PB3.Signal=SPI1_SCK
PB4.Signal=SPI1_MISO
PB5.Signal=SPI1_MOSI
PB8.Signal=I2C1_SCL
PB9.Signal=I2C1_SDA
PC14-OSC32_IN.Signal=RCC_OSC32_IN
PC15-OSC32_OUT.Signal=RCC_OSC32_OUT

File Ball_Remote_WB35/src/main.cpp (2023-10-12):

#include "initialisation.h"
#include "BleApp.h"
#include "BasService.h"
#include "HidService.h"
#include "app_entry.h"
#include "USB.h"
#include "gyroSPI.h"
#include "led.h"
#include "configManager.h"

/* TODO
 * Test USB wake up and sleep
 * Test sleep clock settings
 *
 */

volatile uint32_t SysTickVal;
bool usbStarted = false;

int main(void)
{
	InitClocks();					// Set system clocks
	InitHardware();					// Initialise HSEM, IPCC, RTC, EXTI
	config.RestoreConfig();			// Restore config settings from flash
	gyro.Setup();					// Setup address and settings for gyroscope
	APPE_Init();					// Initialise low level BLE functions and schedule start of BLE

	while (1) {
		if (!bleApp.coprocessorFailure) {
			RunPendingTasks();
		}
		usb.cdc.ProcessCommand();	// Check for incoming CDC commands
		basService.TimedRead();		// Updates battery level every few seconds if changed
		if (basService.level == 100 && !usbStarted) {
			usb.InitUSB();			// Start usb only when powered by USB
			usbStarted = true;
		}
		led.Update();				// Check if LED needs to be updated (flashing etc)
	}
}

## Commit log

2021-11-26 Directly initialise IPCC peripheral; cleaned up interrupt handers
2021-11-26 Converted RTC initialisation from HAL; fixed some clock issues when cold starting
    [initialisation.cpp, main.cpp]
2021-11-27 Removed HAL dependencies for UART; UART receive working
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2021-12-04 Implemented basic method to read magnetometer headings via I2C
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2021-12-06 Decoded I2c compass data; implemented continuous capture at ~1kHz
2021-12-09 Updated base unit to support 3 channels of HID to PWM
    [Ball_Base_Components.kicad_sch]
2021-12-20 Fixed issues caused by incorrect PMA address in ST headers
    [USB.cpp, USB.h, stm32wbxx_it.cpp]
2021-12-23 Updates to use usb for printf; Start implementing diagnostic device discovery
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2021-12-27 More attempts to work around print issues
    [app_ble.cpp]
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2022-01-18 Refactoring; experiments with workarounds for fus/coprocessor update breaking usb
    [USB.cpp, USB.h, app_ble.cpp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]
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2022-01-26 Implemented shutdown and reboot mode; more work on sleep mechanism
    refactoring of service control, making hids, bas and dis consistent classes
    [app_ble.cpp, app_ble.h, initialisation.cpp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]
2022-01-28 Added various i2c debug commands; started looking at support for ST L3GD20 gyroscope
2022-02-06 Started implementing control mechanism with calibration and offset handling
2022-02-08 Added console info function to view current settings; Minor tweaks
2022-02-10 Calibration updates; I2C Handling improvements; Started Base Schematic
    [Ball_Base_Components.kicad_sch]
2022-02-14 Rough Ball Base PCB layout
    [Ball_Base_Components.kicad_pcb, Ball_Base_Components.kicad_sch]
2022-02-17 First draft of Ball Base pcb completed
    [Ball_Base_Components.kicad_pcb, Ball_Base_Components_spare_filter.kicad_sch]
2022-02-18 Base PCB Updates and resize
    [Ball_Base_Components.kicad_pcb, Ball_Base_Components.kicad_sch]
2022-02-19 Base - started panel PCB
    [Ball_Base_Components.kicad_pcb, Ball_Base_Components.kicad_sch]
2022-02-23 Minor PCB Updates
    [Ball_Base_Components.kicad_pcb, Ball_Base_Components.kicad_sch]
2022-02-23 More PCB Clean up
    [Ball_Base_Components.kicad_pcb, Ball_Base_Components.kicad_sch]
2022-02-24 PCB Updates
    [Ball_Base_Components.kicad_pcb, Ball_Base_Components.kicad_sch]
2022-02-27 Started layout of Ball Remote schematic
    [Ball_Remote_Components.kicad_pcb, Ball_Remote_Components.kicad_sch]
2022-03-05 Work on remote PCB
    [Ball_Remote_Components.kicad_pcb, Ball_Remote_Components.kicad_sch]
2022-03-13 Remote schematic and PCB clean up
    [Ball_Base_Components-B_Cu.gbr, Ball_Base_Components-B_Mask.gbr, Ball_Base_Components-B_Paste.gbr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]
2022-03-14 More PCB clean-up
    [Ball_Remote_Components.kicad_pcb, Ball_Remote_Components.kicad_sch, Ball_Solder_Stencil.kicad_pcb]
2022-03-22 Preparation of Gerbers for manufacturing
    [Ball_Base_Components-B_Cu.gbr, Ball_Base_Components-B_Mask.gbr, Ball_Base_Components-B_Paste.gbr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]
2022-03-22 Updated panel to reduce copper pour and solder mask
    [Ball_Base_Panel-B_Cu.gbr, Ball_Base_Panel-B_Mask.gbr, Ball_Base_Panel-B_Paste.gbr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]
2022-03-23 Fixed 4-layer marker incorrect copper layers
    [Ball_Base_Components.kicad_pcb, Ball_Remote_Components.kicad_pcb]
2022-06-21 Created test firmware for STM32WB35 hardware (not yet working)
    [Ball_Base_Components.kicad_sch, Ball_Remote_Components.kicad_pcb, Ball_Remote_Components.kicad_sch]
2022-06-25 Testing with prototype remote hardware; implemented battery level monitor
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2023-08-29 Preparing to test Remote board
    [Ball_Remote_Components.kicad_pcb, Ball_Remote_Components.kicad_sch]
2023-09-03 Updating Gyroscope code to use SPI
    Basic communication with Gyro SPI working; DMA not yet implemented
    [Adafruit_Gyro_Module.kicad_pcb, Adafruit_Gyro_Module.kicad_sch, Ball_Remote_Components.kicad_sch]
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2023-09-05 Updated production code to support Gyro SPI
    Started updating USB code; basic timer notification working
2023-09-06 Added Battery Voltage output to BAS service
    Fixed RSSI output
    Fixed bug sequencing gyro SPI reads
    [Ball_Remote_Components.kicad_sch]
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2023-09-06 Battery level checked periodically and updated if required
2023-09-07 Joystick and Battery Notifications triggered by sequencer to avoid lockups
    [app_conf.h]
2023-09-08 Updated notification task type to attempt to resolve crashes
    [app_ble.cpp, app_conf.h, initialisation.cpp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]
2023-09-08 More library files updated
    [Ball_Remote_Components.kicad_pcb]
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2023-09-09 Cleaned up schematic to fix issues in Kicad 7; refactored USBClass to USBMain
    [Ball_Remote_Components.kicad_sch]
2023-09-11 Starting to update Base firmware
    [Ball_Base_Components.kicad_sch]
2023-09-13 Updated library files and fixed connection issue
    [app_ble.cpp, app_conf.h]
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2023-09-13 Fixed CDC hidmap function
    [CDCHandler.cpp, app_ble.cpp]
2023-09-18 Fixes to USB CDC corruptions and missing data
    [CDCHandler.cpp, USB.cpp, app_ble.cpp]
2023-09-18 Cleaned up connection code; added battery level request
2023-09-19 Auto calibrate on startup
    Cleaned up status output
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2023-09-22 Updated remote usb to fix transmission glitches
    [CDCHandler.cpp, USB.cpp, USB.h]
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2023-09-24 Added mechanism to read and write gyroscope registers over BLE from Base
2023-09-25 Updates to mechanism to read/write gyro registers from base
    Not fully working - when reading notification not always received
2023-09-26 More tweaks to gyro register reading/writing
    Still not working properly
2023-09-26 Project clean up; split gyro register into command and data
2023-09-26 Gyro register reading/writing from base working
    Though hacky - has to periodically read to get values as notifications getting lost
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2023-09-28 Removed old projects; 'Connect' button now controls sleep state
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2023-09-30 Sleep mode on remote with wake-up from gyro interrupt working
    Currently triggered from usb command but need to implement with no motion timer
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2023-10-01 Started configuring gyro ready to EXT interrupt
    [Ball_Remote_Components.kicad_sch]
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2023-10-03 Potentially fixed issue initialising RTC wake up interrupt
    [BleApp.cpp, BleApp.h, initialisation.cpp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]
2023-10-03 Fixed wake up from sleep using wrong clock
    [BleApp.cpp, BleApp.h, CDCHandler.cpp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]
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2023-10-04 Use Data Ready pin on Gyroscope to trigger read (rather than timer)
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2023-10-05 Shutdown if battery falls below configurable level
    [Ball_Remote_Components.kicad_sch]
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2023-10-07 Base will periodically wake up remote to check battery level and flash if battery low
    Removed offsets from base as handled in remote
    Added config for battery warnings and sensitivity
    [Ball_Remote_Components.kicad_pcb, Ball_Remote_Components.kicad_sch]
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2023-10-12 Experiments with USB disabled current consumption; added invert to z axis
    [BleApp.cpp, BleApp.h, CDCHandler.cpp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]
2023-10-12 Remote: only activate USB peripheral when powered
    [Ball_Remote_Components.kicad_sch]
2023-10-12 Added option to choose between HSI and HSE in sleep mode
    HSI is more power efficient, but sometimes has problems waking up
    [BleApp.cpp, BleApp.h, CDCHandler.cpp]
2023-10-13 Added schematic pdfs
    [Ball_Base_Components.kicad_sch, Ball_Remote_Components.kicad_sch]
